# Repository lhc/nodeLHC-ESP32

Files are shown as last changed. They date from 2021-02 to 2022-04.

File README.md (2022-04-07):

## nodeLHC

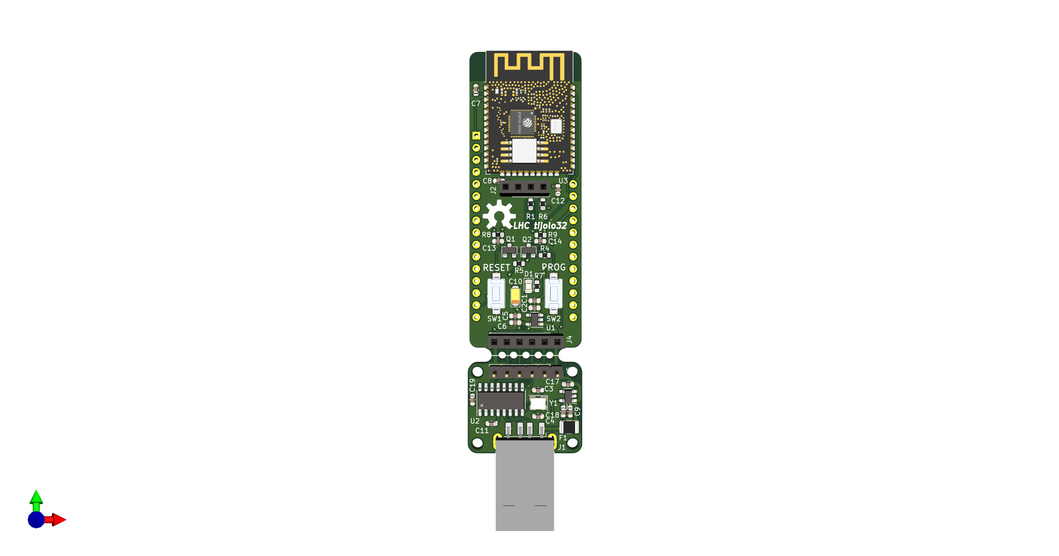
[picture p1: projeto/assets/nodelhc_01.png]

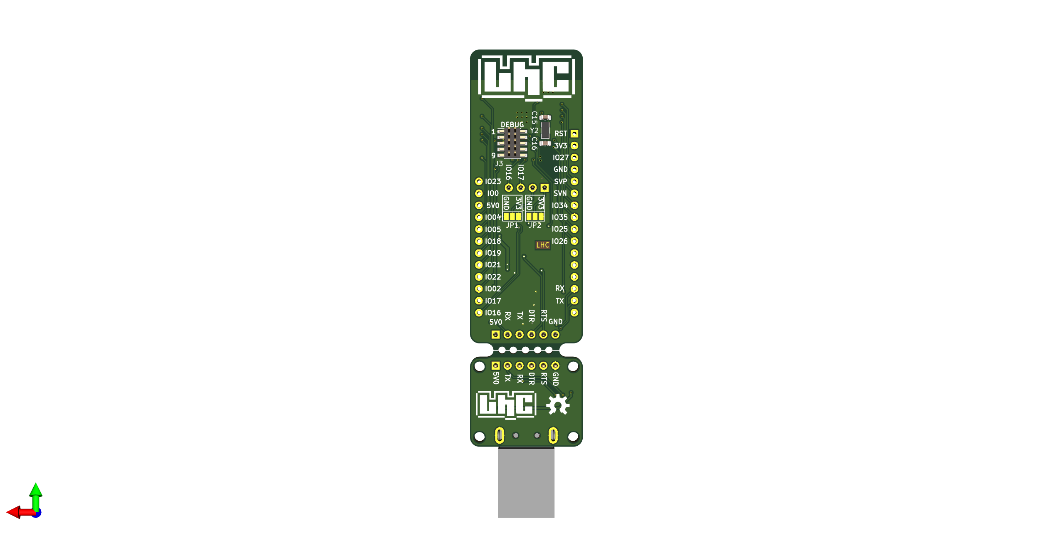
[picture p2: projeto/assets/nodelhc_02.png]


# nodeLHC-ESP32







LIVE em formato Hands On Construindo o nova versão da placa de desenvolvimento nodeLHC ESP32, com o Pedro Minatel, utilizando a ferramenta Kicad, o módulo escolhido foi o ESP32 um microcontrolador de baixo custo da Espressif.

Em 2015 durante as oficinas de IoT no Hackerspace, criamos uma primeira versão do nodeLHC com o módulo ESP8266. Assim as pessoas aprenderam as diferentes etapas para construção de placa de circuitos impressos, também soldagem dos componentes da placa de desenvolvimento e programação para o módulo.

Descrições e detalhes:
Essa é uma primeira atividade que ao decorrer iremos construir novos projetos no formato aberto e colaborativo aproveitando a placa de desenvolvimento nodeLHC ESP32

- [KiCad](https://kicad.org/)
- [LHC KiCad Library](https://github.com/lhc/lhc_kicad_library)
- [Minatel KiCad Library](https://github.com/pedrominatel/minatel-kicad-libraries)
- [SparkFun KiCad Library](https://github.com/sparkfun/SparkFun-KiCad-Libraries)

# Checklist
- [x] LIVE 1 - Explicação geral e desenho
- [x] LIVE 2 - Revisão esquemático e desenho da PCB parcial
- [x] Lista de pessoas interessadas nos módulos
- [x] [20/11 às 20 horas : Feedback comunidade](https://discourse.lhc.net.br/t/parte-03-20-11-2020-coleta-de-feedback-do-nodelhc-esp32/225)
- [x] [LIVE 3 no dia 22 de janeiro de 2021 - Finalizar placa com KiCad](https://discourse.lhc.net.br/t/parte-05-finalizando-o-nodelhc-esp32-com-kicad/244)
- [x] Enviado o e-mail de confirmação aos interessados ao módulos ESP32
- [x] [Lista de interessados na compra coletiva](https://docs.google.com/forms/d/11yyAbOFoUoV5jsIAHc90laWFHk0OwfYHXRMlwPwyAws/edit)
- [x] Reunião online para novos revisores.
- [x] Validar artes na PCB (LHC/ Open Hardware)
- [x] [Videoconferência Revisão do nodeLHC: 25 Maio 2021 às 20 horas](meet.google.com/ngs-ypnc-mkd)

# Próximos passos
- [x] Convite Latinoware 2021
- [ ] Listar BOM / Orçamentos
- [ ] Produção da PCB
- [ ] LIVE de soldando o nodeLHC
- [ ] Distribuição para os participantes

# Checklist Review 01 nodeLHC

| Itens | Check | Double Check  |
|---|---|---|
| Alimentação 3V3| [Fechado](https://github.com/lhc/nodeLHC-ESP32/issues/2) | [Fechado](https://github.com/lhc/nodeLHC-ESP32/issues/9) |
| RX/TX| [Fechado](https://github.com/lhc/nodeLHC-ESP32/issues/3) | [Fechado](https://github.com/lhc/nodeLHC-ESP32/issues/10) |
| Reset e Boot| [Fechado](https://github.com/lhc/nodeLHC-ESP32/issues/4) | [Fechado](https://github.com/lhc/nodeLHC-ESP32/issues/11) |
| Conversor USB para UART| [Fechado](https://github.com/lhc/nodeLHC-ESP32/issues/5) | [Fechado](https://github.com/lhc/nodeLHC-ESP32/issues/12) |
| Conector Debug/JTAG| [Fechado](https://github.com/lhc/nodeLHC-ESP32/issues/6) | [Fechado](https://github.com/lhc/nodeLHC-ESP32/issues/13) |
| OLED| [Fechado](https://github.com/lhc/nodeLHC-ESP32/issues/7) | [Fechado](https://github.com/lhc/nodeLHC-ESP32/issues/14) |
| ESP32-WROMM pinout| [Fechado](https://github.com/lhc/nodeLHC-ESP32/issues/8) | [Fechado](https://github.com/lhc/nodeLHC-ESP32/issues/15) |

# Revisores
- Daniel
- Adrian
- Manassés
- Douglas

## Bill of Materials
| Component | Quantity | Link |
|---|---|---|
| ESP32-WROOM- | 1 | |
|  | | |

[Clique aqui](https://htmlpreview.github.io/?https://github.com/lhc/nodeLHC-ESP32/blob/master/projeto/bom/ibom.html) para ver a BOM interativa

Para gerar a BOM interativa, é necessário [instalar o plugin no KiCad](https://github.com/openscopeproject/InteractiveHtmlBom/wiki/Installation) e seguir as [orientações de uso](https://github.com/openscopeproject/InteractiveHtmlBom/wiki/Usage)

Para utilizar o plugin, no KiCad 6.x, após instalação concluída, utilize `PCB Editor > Tools > External Plugins > Generate Integractive HTML BOM`

# Vídeos gravados
- [Construindo o nodeLHC ESP32 com Kicad - Parte 01 #nodeLHC](https://youtu.be/l77AwA57H2A?t=1641)
- [Construindo o nodeLHC ESP32 com Kicad - Parte 02 #nodelhc](https://www.youtube.com/watch?v=WE6jsmoJX9M)
- [Construindo o nodeLHC ESP32 com Kicad - Parte 05](https://www.youtube.com/watch?v=1r1fcpELneA)

# Discourse
Dúvidas? sugestões publicar na issues ou direto no discourse do LHC
- [Parte 01 - 28/07/2020 LIVE - Hands On: Construindo o nodeLHC ESP32 com Kicad](https://discourse.lhc.net.br/t/28-07-2020-live-hands-on-construindo-o-nodelhc-esp32-com-kicad/148/2)
- [Parte 02 - Hands On: Construindo o nodeLHC ESP32 com Kicad](https://discourse.lhc.net.br/t/11-09-2020-live-hands-on-construindo-o-nodelhc-esp32-com-kicad-parte-02/160)
- [Parte 03 - Feedback comunidade](https://discourse.lhc.net.br/t/parte-03-20-11-2020-coleta-de-feedback-do-nodelhc-esp32/225)
- [Parte 04 - Melhorias para o nodeLHC ESP32](https://discourse.lhc.net.br/t/parte-04-melhorias-para-o-nodelhc-esp32/230/2)
- [Parte 05 - 22/01 às 20 horas: Hands On: Construindo o nodeLHC ESP32 com Kicad](https://discourse.lhc.net.br/t/parte-05-finalizando-o-nodelhc-esp32-com-kicad/244)

# Documentações em outras plataformas
- [Hackday.io](https://hackaday.io/project/177704-lhc-tijolo32-esp32-development-board)

# Log
- 19/08/2020 - Criado o evento, repositório, publicações nas redes sociais gerado link sobre a atividade.
- 02/09/2020 - Criado, divulgado o segundo evento, atualização de links no repositório.
- 06/10/2020 - Listagem das pessoas que responderam o discourse para receber o módulo ESP32
- 07/10/2020 - Chegaram os módulos.
- 17/11/2020 - Agendada conversa de feedback do projeto, divulgação da atividade.
- 16/01/2021 - Pedro fez update conforme o último encontro de feedback.
- 17/01/2021 - Atualizado no repositório, criado agenda de LIVE para o dia 22 de janeiro de 2021.
- 07/02/2021 - Enviado e-mail aos interessados aos módulos
             - Divulgação da compra coletiva de componentes para o nodeLHC
- 11/03/2021 - Atualização de revisão e update no projeto
- 16/03/2021 - Atualização de imagens e links de gravações
- 30/05/2021 - Feedback do Daniel registrado e atualização no README.md

### Referências
- [ESP32 Datasheet](https://www.espressif.com/sites/default/files/documentation/esp32_datasheet_en.pdf)
- [ESP32-WROOM Datasheet](https://www.espressif.com/sites/default/files/documentation/esp32-wroom-32d_esp32-wroom-32u_datasheet_en.pdf)
- [ESP32 Design Guidelines](https://www.espressif.com/sites/default/files/documentation/esp32_hardware_design_guidelines_en.pdf)
- [CH340G](https://cdn.sparkfun.com/datasheets/Dev/Arduino/Other/CH340DS1.PDF)
- [Open Source Hardware Association](https://www.oshwa.org/definition/)

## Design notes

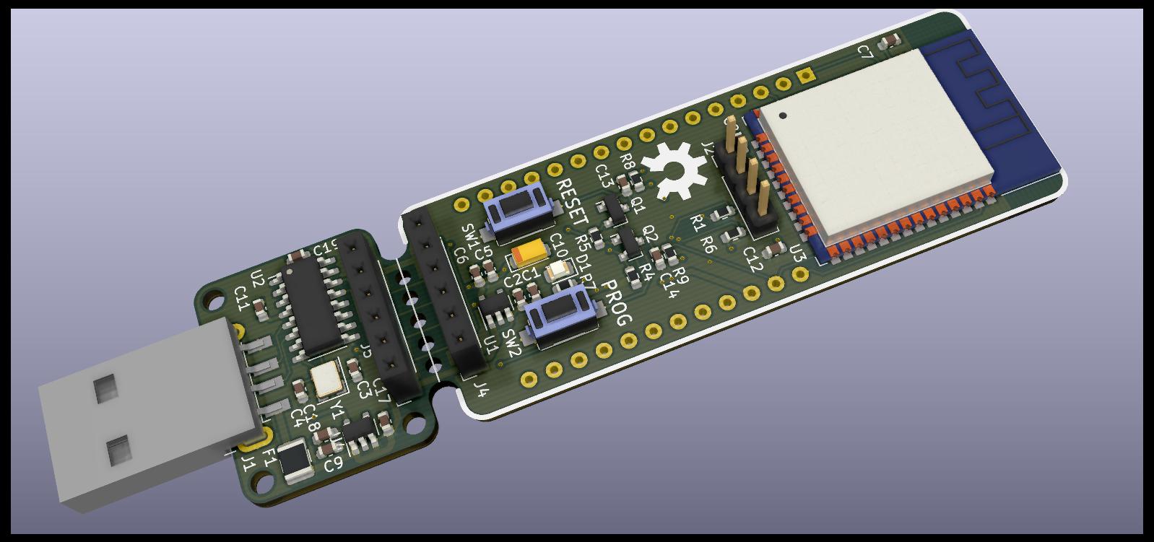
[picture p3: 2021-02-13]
projeto/assets/lhc_tijolo32_board_bot.jpg

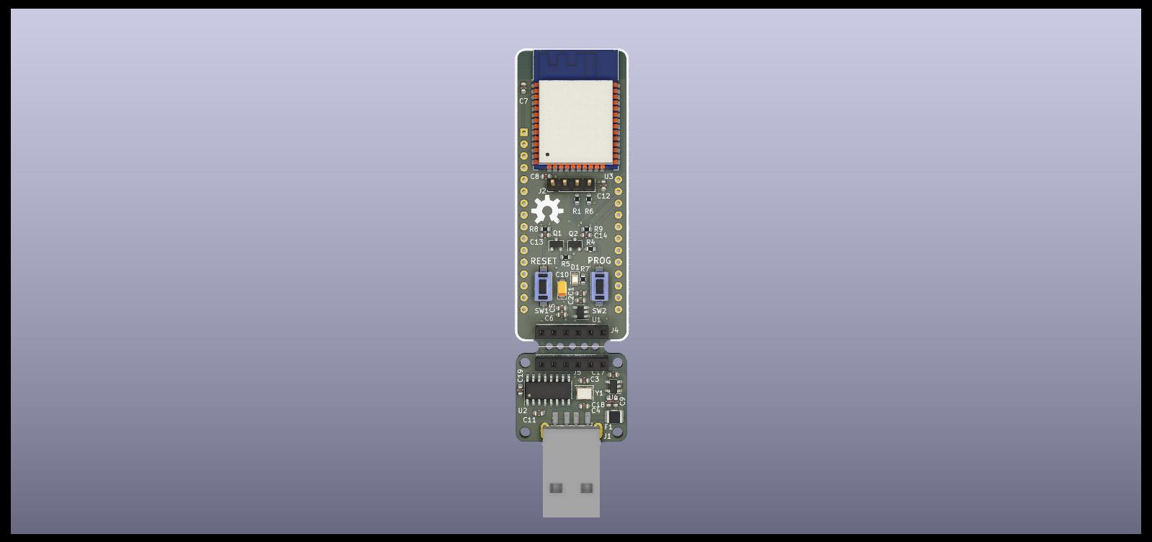
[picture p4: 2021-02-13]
projeto/assets/lhc_tijolo32_board.jpg

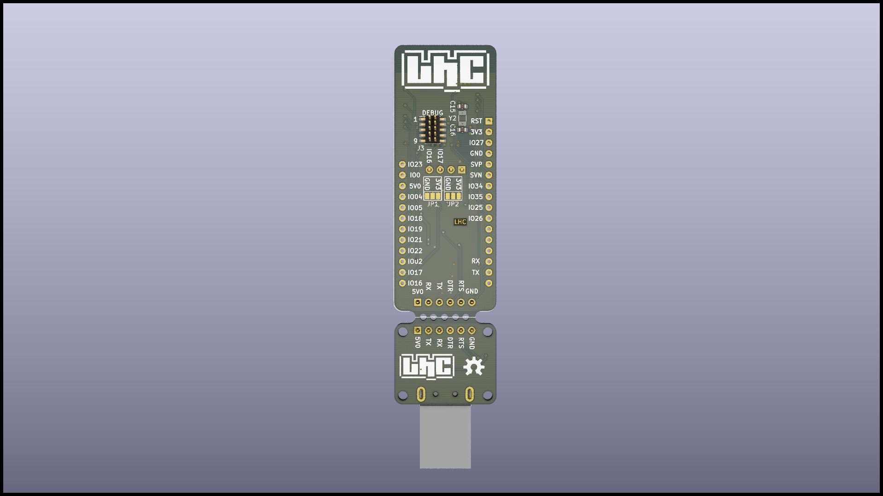
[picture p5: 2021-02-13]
projeto/assets/lhc_tijolo32_board2.jpg

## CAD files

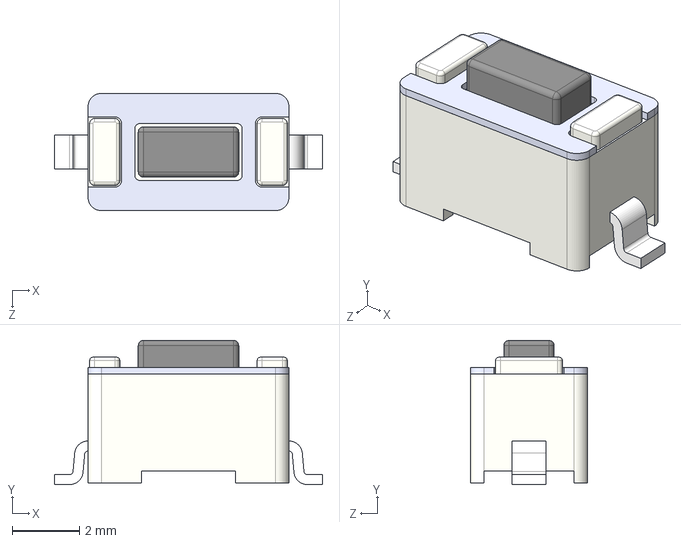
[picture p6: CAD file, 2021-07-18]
projeto/assets/3d/RS-032G05A3-SM RT--3DModel-STEP-56544.STEP
8.00 x 4.30 x 3.50 mm

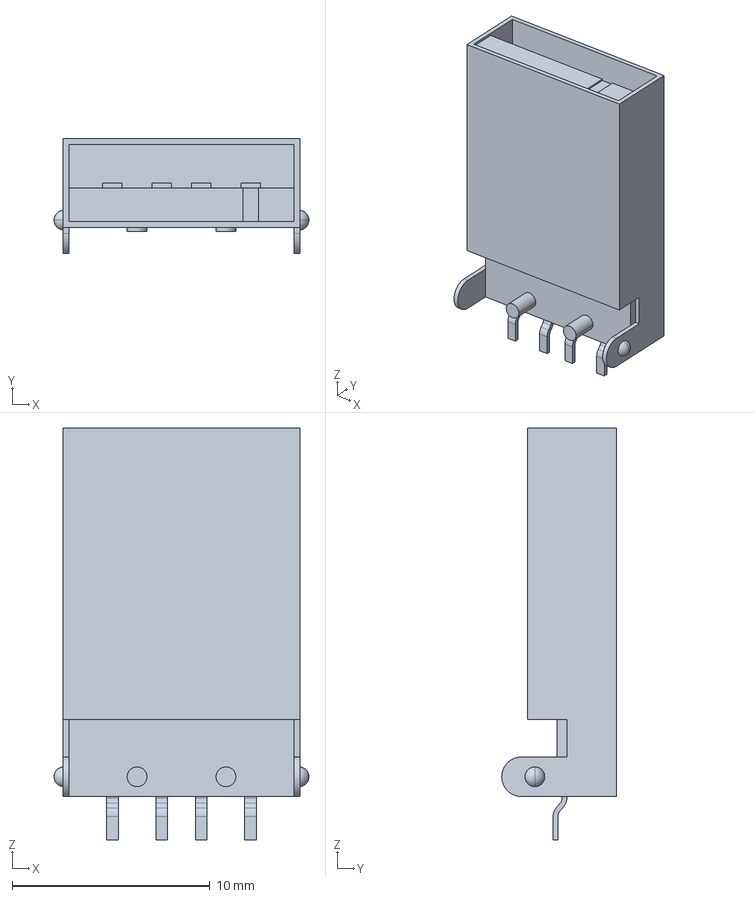
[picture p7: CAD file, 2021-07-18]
projeto/assets/3d/1-1734028-1.stp
12.9 x 5.80 x 20.9 mm

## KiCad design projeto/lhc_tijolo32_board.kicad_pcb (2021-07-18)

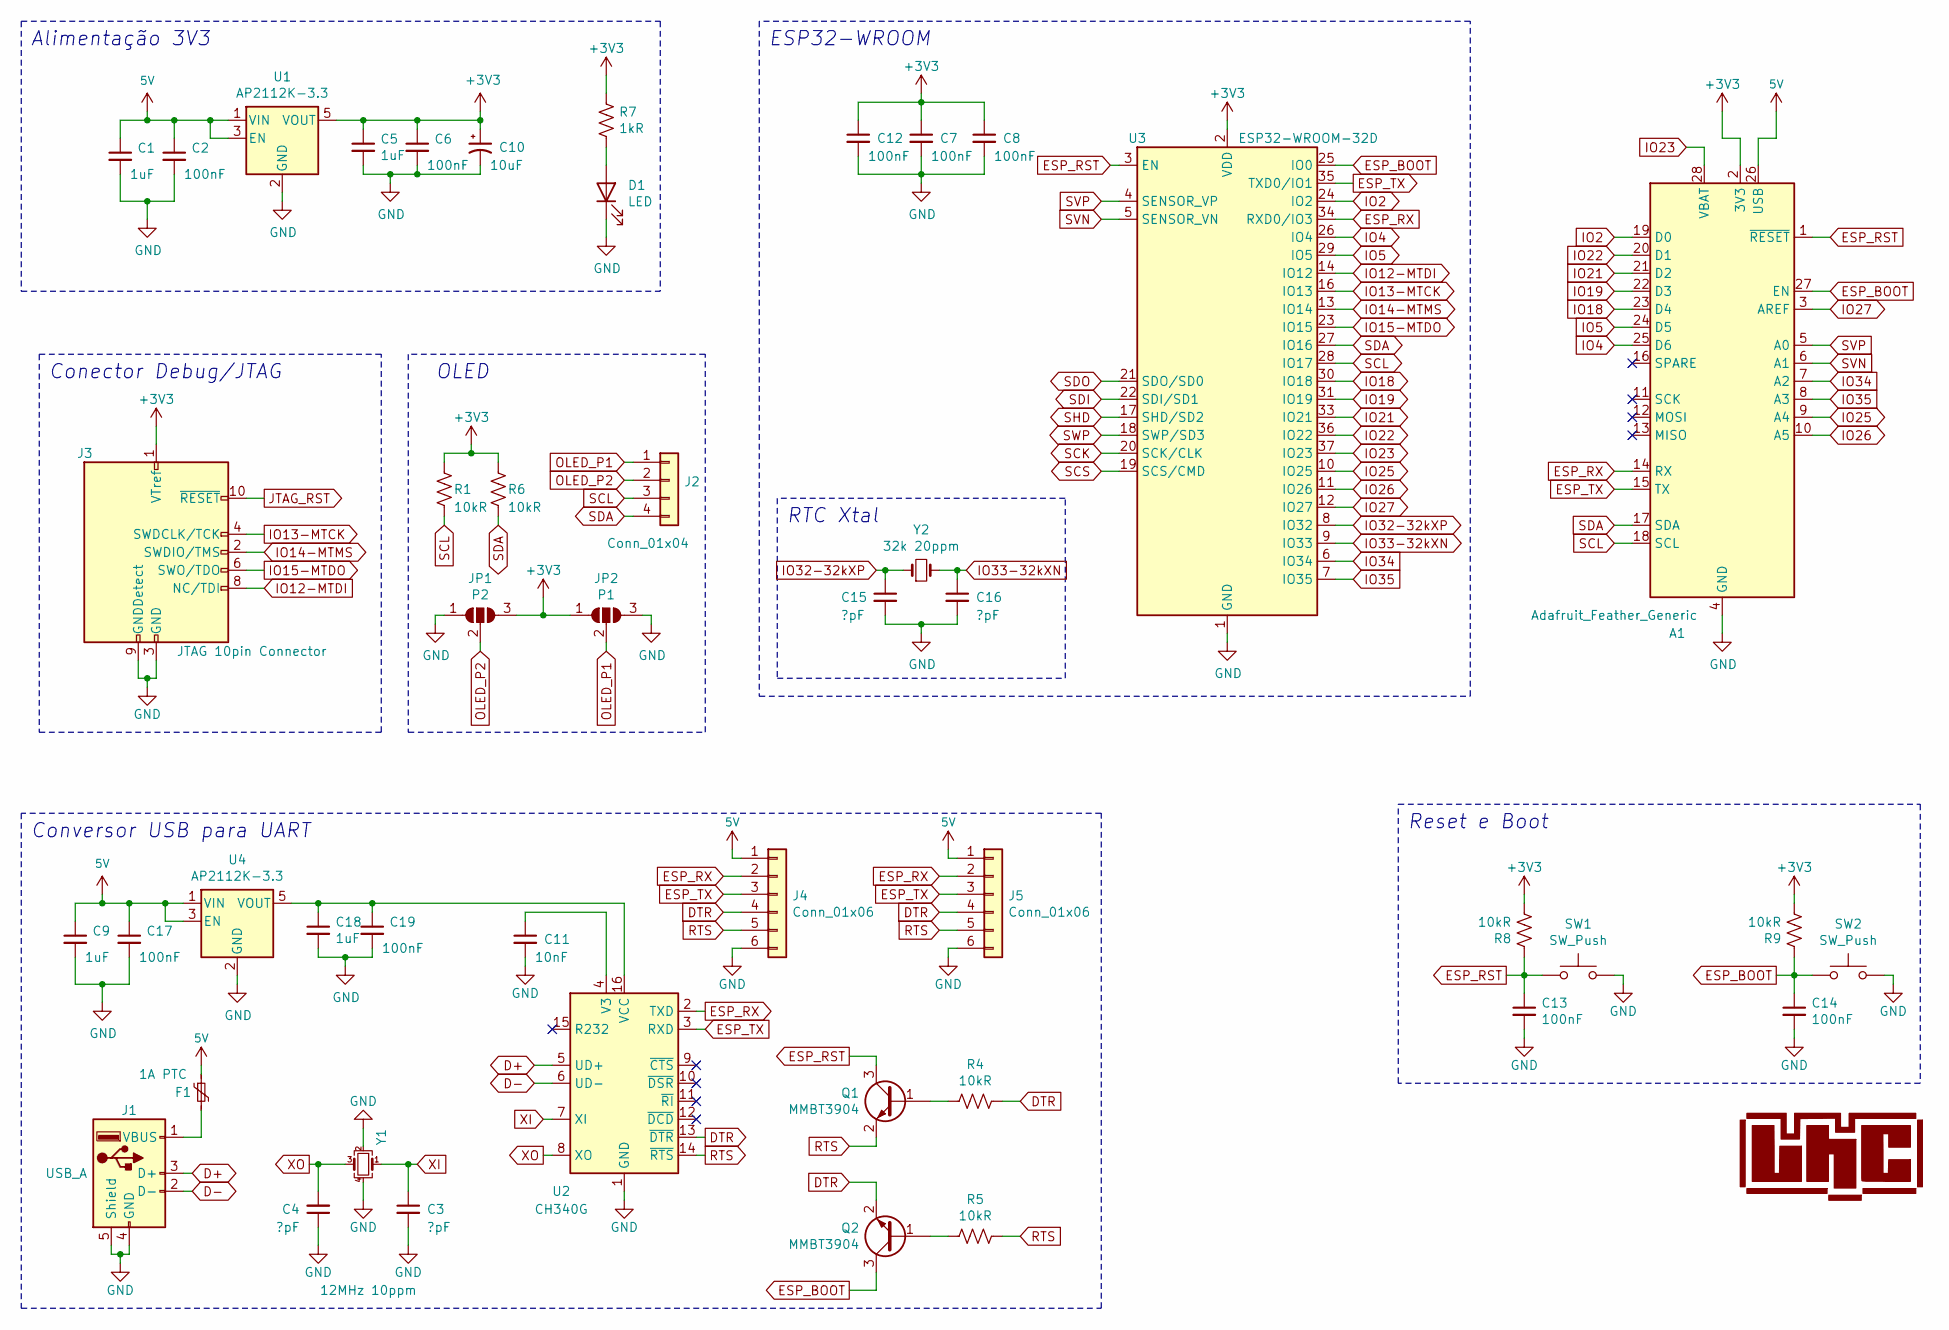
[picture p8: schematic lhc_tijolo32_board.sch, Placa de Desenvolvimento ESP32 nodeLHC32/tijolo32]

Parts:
A1: Adafruit_Feather_Generic; Adafruit_Feather
C1, C5, C9, C18: 1uF; C_0603_1608Metric
C2, C6, C7, C8, C12, C13, C14, C17, C19: 100nF; C_0603_1608Metric
C3, C4, C15, C16: ?pF; C_0603_1608Metric
C10: 10uF; CP_EIA-3216-12_Kemet-S; LCSC C7171
C11: 10nF; C_0603_1608Metric
D1: LED; LED_0805_2012Metric
F1: 1A PTC; R_1210_3225Metric
J1: USB_A; USB_A_CNCTech_1001-011-01101_Horizontal
J2: Conn_01x04; PinSocket_1x04_P2.54mm_Vertical
J3: JTAG 10pin Connector; PinHeader_2x05_P1.27mm_Vertical_SMD
J4, J5: Conn_01x06; PinSocket_1x06_P2.54mm_Vertical
JP1: P2; SolderJumper-3_P1.3mm_Open_Pad1.0x1.5mm_NumberLabels
JP2: P1; SolderJumper-3_P1.3mm_Open_Pad1.0x1.5mm_NumberLabels
Q1, Q2: MMBT3904; SOT-23
R1, R4, R5, R6, R8, R9: 10kR; R_0603_1608Metric
R7: 1kR; R_0603_1608Metric
SW1, SW2: SW_Push; TACTILE_SWITCH_SMD_6.0X3.5MM
U1, U4: AP2112K-3.3; SOT-23-5
U2: CH340G; SOIC-16_3.9x9.9mm_P1.27mm; MPN C14267
U3: ESP32-WROOM-32D; ESP32-WROOM-32
Y1: 12MHz 10ppm; Crystal_SMD_EuroQuartz_MT-4Pin_3.2x2.5mm
Y2: 32k 20ppm; Crystal_SMD_3215-2Pin_3.2x1.5mm

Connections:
5V: A1.26 (USB), C1.1, C2.1, C9.1, C17.1, F1.1, J4.1, J5.1, U1.1 (VIN), U1.3 (EN), U4.1 (VIN), U4.3 (EN)
+3V3: A1.2 (3V3), C5.1, C6.1, C7.1, C8.1, C10.1, C12.1, J3.1 (VTref), JP1.3 (B), JP2.1 (A), R1.1, R6.1, R7.1, R8.2, R9.2, U1.5 (VOUT), U3.2 (VDD)
D+: J1.3 (D+), U2.5 (UD+)
D-: J1.2 (D-), U2.6 (UD-)
DTR: J4.4, J5.4, Q2.2 (E), R4.1, U2.13 (~DTR)
ESP_BOOT: A1.27 (EN), C14.1, Q2.3 (C), R9.1, SW2.1, U3.25 (IO0)
ESP_RST: A1.1 (~RESET), C13.1, Q1.3 (C), R8.1, SW1.1, U3.3 (EN)
ESP_RX: A1.14 (RX), J4.2, J5.2, U2.2 (TXD), U3.34 (RXD0/IO3)
ESP_TX: A1.15 (TX), J4.3, J5.3, U2.3 (RXD), U3.35 (TXD0/IO1)
GND: A1.4 (GND), C1.2, C2.2, C3.2, C4.1, C5.2, C6.2, C7.2, C8.2, C9.2, C10.2, C11.2, C12.2, C13.2, C14.2, C15.2, C16.2, C17.2, C18.2, C19.2, D1.1 (K), J1.4 (GND), J1.5 (Shield), J3.3 (GND), J3.5 (GND), J3.9 (GNDDetect), J4.6, J5.6, JP1.1 (A), JP2.3 (B), SW1.2, SW2.2, U1.2 (GND), U2.1 (GND), U3.1 (GND), U3.15 (GND), U3.38 (GND), U3.39 (GND), U4.2 (GND), Y1.2, Y1.4
IO2: A1.19 (D0), U3.24 (IO2)
IO4: A1.25 (D6), U3.26 (IO4)
IO5: A1.24 (D5), U3.29 (IO5)
IO12-MTDI: J3.8 (NC/TDI), U3.14 (IO12)
IO13-MTCK: J3.4 (SWDCLK/TCK), U3.16 (IO13)
IO14-MTMS: J3.2 (SWDIO/TMS), U3.13 (IO14)
IO15-MTDO: J3.6 (SWO/TDO), U3.23 (IO15)
IO18: A1.23 (D4), U3.30 (IO18)
IO19: A1.22 (D3), U3.31 (IO19)
IO21: A1.21 (D2), U3.33 (IO21)
IO22: A1.20 (D1), U3.36 (IO22)
IO23: A1.28 (VBAT), U3.37 (IO23)
IO25: A1.9 (A4), U3.10 (IO25)
IO26: A1.10 (A5), U3.11 (IO26)
IO27: A1.3 (AREF), U3.12 (IO27)
IO32-32kXP: C15.1, U3.8 (IO32), Y2.1
IO33-32kXN: C16.1, U3.9 (IO33), Y2.2
IO34: A1.7 (A2), U3.6 (IO34)
IO35: A1.8 (A3), U3.7 (IO35)
JTAG_RST: J3.10 (~RESET~)
unnamed: C11.1, U2.4 (V3)
unnamed: C18.1, C19.1, U2.16 (VCC), U4.5 (VOUT)
unnamed: D1.2 (A), R7.2
unnamed: F1.2, J1.1 (VBUS)
unnamed: Q1.1 (B), R4.2
unnamed: Q2.1 (B), R5.2
OLED_P1: J2.1, JP2.2 (C)
OLED_P2: J2.2, JP1.2 (C)
RTS: J4.5, J5.5, Q1.2 (E), R5.1, U2.14 (~RTS)
SCK: U3.20 (SCK/CLK)
SCL: A1.18 (SCL), J2.3, R1.2, U3.28 (IO17)
SCS: U3.19 (SCS/CMD)
SDA: A1.17 (SDA), J2.4, R6.2, U3.27 (IO16)
SDI: U3.22 (SDI/SD1)
SDO: U3.21 (SDO/SD0)
SHD: U3.17 (SHD/SD2)
SVN: A1.6 (A1), U3.5 (SENSOR_VN)
SVP: A1.5 (A0), U3.4 (SENSOR_VP)
SWP: U3.18 (SWP/SD3)
XI: C3.1, U2.7 (XI), Y1.1
XO: C4.2, U2.8 (XO), Y1.3

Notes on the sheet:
Alimentação 3V3
Conversor USB para UART
Conector Debug/JTAG
Reset e Boot
OLED
ESP32-WROOM
RTC Xtal

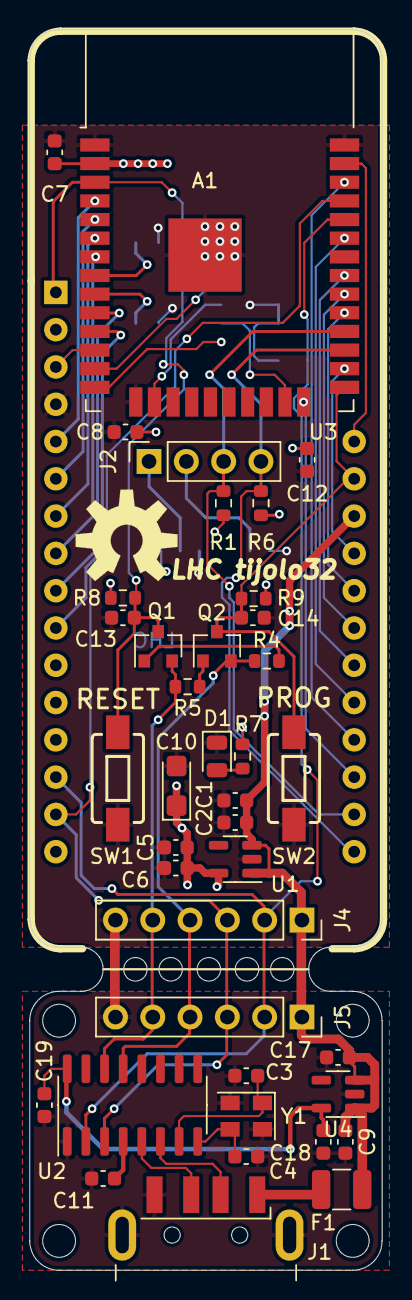
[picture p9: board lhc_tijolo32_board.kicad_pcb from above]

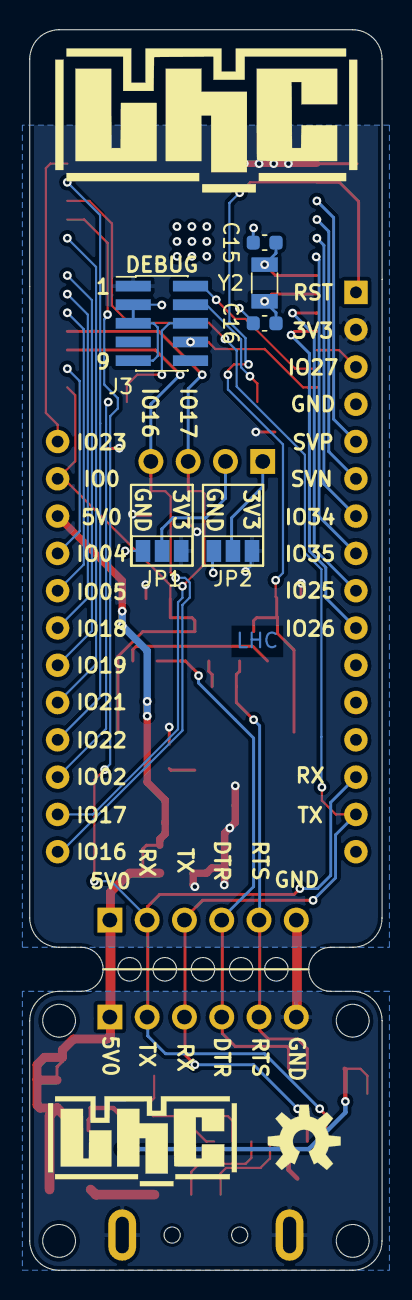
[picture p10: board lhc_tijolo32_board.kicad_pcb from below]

Board: 2 copper layers, 24.0 x 84.5 mm, 46 parts (6 on the bottom side), 44 nets.

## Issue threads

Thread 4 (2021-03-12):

Check - Reset e Boot

EstevesDouglas, 2021-03-12:
Contribua com revisões no esquemático e footprint do projeto.

Checklist nodeLHC review - check - Reset e Boot

EstevesDouglas, 2021-05-01:
Ok.

Closed 2021-05-01.

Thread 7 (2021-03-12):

Check - OLED

EstevesDouglas, 2021-03-12:
Contribua com revisões no esquemático e footprint do projeto.

Checklist nodeLHC review - check - OLED

EstevesDouglas, 2021-05-01:
Uma dúvida sobre o display OLED.

@pedrominatel confirmando a questão da possibilidade de inverter o p1 e p2 do OLED direto na placa.
Ela fica padrão?
GND
VCC
SCL
SDA
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

Segue a imagem de alguns Displays OLED que tenho aqui para confirmar o pinout.
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

EstevesDouglas, 2021-05-09:
Ok.

Closed 2021-05-09.

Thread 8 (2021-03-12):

Check - ESP32-WROMM pinout

EstevesDouglas, 2021-03-12:
Contribua com revisões no esquemático e footprint do projeto.

Checklist nodeLHC review - check - ESP32-WROMM pinout

EstevesDouglas, 2021-05-01:
Ok.

Closed 2021-05-01.

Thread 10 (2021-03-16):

Double Check -  RX/TX

EstevesDouglas, 2021-03-16:
Contribua com revisões no esquemático e footprint do projeto.

Checklist nodeLHC review - Double Check - RX/TX

EstevesDouglas, 2021-05-30:
via Daniel Vieira
Os pinos rx e tx estão conectados de forma correta, já estão ligados invertidos na placa, então na hora de ligar é só ligar, não precisa inverter.

Closed 2021-05-30.

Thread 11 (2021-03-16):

Double Check - Reset e Boot

EstevesDouglas, 2021-03-16:
Contribua com revisões no esquemático e footprint do projeto.

Checklist nodeLHC review - double check - Reset e Boot

EstevesDouglas, 2021-05-30:
via Daniel Vieira
O circuito de gravação do ESP está ok também, tem o botão de boot, uma vez que caso os transistores não realizem  o chaveamento, pode se gravar pressionando o botão ESP boot e enable é habilitado pelo transistor.

Closed 2021-05-30.

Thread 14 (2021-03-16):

Double Check - OLED

EstevesDouglas, 2021-03-16:
Contribua com revisões no esquemático e footprint do projeto.

Checklist nodeLHC review - double check - OLED

pedrominatel, 2021-05-09:
Quais são os modelos mais utilizados de OLED?

https://www.filipeflop.com/produto/display-oled-0-96-polegadas-i2c-azul/
https://www.filipeflop.com/produto/display-oled-0-96-i2c-azul-amarelo/

EstevesDouglas, 2021-05-09:
Pelo que eu andei pesquisando aqui é esse Azul o mais usado.

Mas o legal que eles seguem o mesmo padrão.

EstevesDouglas, 2021-05-30:
via Daniel Vieira
Eu fiz a revisão do esquemático da pcb do ESP 32 o jumper do display oled ficou bom, pois tem displays que o pino gnd e vc estão invertidos conforme as figuras.

Closed 2021-05-30.

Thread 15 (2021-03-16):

Double Check - ESP32-WROMM pinout

EstevesDouglas, 2021-03-16:
Contribua com revisões no esquemático e footprint do projeto.

Checklist nodeLHC review - double check - ESP32-WROMM pinout

EstevesDouglas, 2021-05-30:
via Daniel Vieira

Closed 2021-05-30.

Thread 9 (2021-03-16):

Double Check - Alimentação 3V3

EstevesDouglas, 2021-03-16:
Contribua com revisões no esquemático e footprint do projeto.

Checklist nodeLHC review - Double Check - Alimentação 3V3

EstevesDouglas, 2021-05-30:
via Daniel Vieira

O circuito de alimentação também está ok.

Closed 2021-05-30.

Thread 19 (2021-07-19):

Atualização da BOM interativa

pedrominatel, 2021-07-19:
Atualizar a BOM interativa com os novos arquivos.

pedrominatel, 2021-07-19:
@EstevesDouglas  tem como dar um help?

EstevesDouglas, 2021-07-19:
Opa! em breve vou atualizar.

manasouza, 2022-01-09:
@pedrominatel e @EstevesDouglas  mandei o PR pra vcs revisarem: https://github.com/lhc/nodeLHC-ESP32/pull/21

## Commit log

2021-01-16 Changed from Sparkfun to Adafruit Feather layout
    [lhc_tijolo32_board.kicad_pcb, lhc_tijolo32_board.sch]
2021-01-16 Layout updated and added new 3d images
    [lhc_tijolo32_board.kicad_pcb, lhc_tijolo32_board.sch]
2021-01-20 Layout updated
    [lhc_tijolo32_board.kicad_pcb, lhc_tijolo32_board.sch]
2021-01-22 Layout improved
    [lhc_tijolo32_board.kicad_pcb, lhc_tijolo32_board.sch]
2021-01-23 Layout LIVE
    [lhc_tijolo32_board.kicad_pcb, lhc_tijolo32_board.sch]
2021-02-13 Updated silk on both sides
    [lhc_tijolo32_board.kicad_pcb]
2021-03-21 add interactive BOM
2021-06-16 Branch for ESP32-S2
2021-07-04 Updated on some labels, footprints and symbols
    [lhc_tijolo32_board.kicad_pcb, lhc_tijolo32_board.sch]
2021-07-18 Componentes 3D adicionados
    [1-1734028-1.stp, RS-032G05A3-SM RT--3DModel-STEP-56544.STEP, lhc_tijolo32_board.kicad_pcb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]
2021-07-18 GERBER atualizado
    [lhc_tijolo32_board-B_Cu.gbr, lhc_tijolo32_board-B_Mask.gbr, lhc_tijolo32_board-B_Paste.gbr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]
2021-07-18 #d dos botoes
    [lhc_tijolo32_board.kicad_pcb]
2021-11-08 Update README.md
    https://forum.kicad.info/t/warning-avoid-all-links-to-kicad-pcb-org-use-kicad-org/31521
2022-01-09 update interactive BOM
2022-01-09 update README with instructions for interactive BOM
